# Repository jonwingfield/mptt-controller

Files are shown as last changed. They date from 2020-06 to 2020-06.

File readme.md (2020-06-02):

# MPTT Charge Controller

Reference Design: http://www.ti.com/tool/TIDA-00120

Better Reference Design: http://www.ti.com/lit/ug/tiduej8a/tiduej8a.pdf?&ts=1588978099192

## Resources

- How Buck Converters work (video is super helpful): https://electronicsforu.com/videos-slideshows/diy-buck-converter-tutorial
- DIY MPTT Charge Controller: http://coder-tronics.com/c2000-solar-mppt-tutorial-pt1/. This explains how to build a buck converter that is very efficient (see notes below).
- Fundamentals of MOSFET Driver circuits: http://www.ti.com/lit/ml/slua618/slua618.pdf
- Another DIY. Very mature https://hackaday.io/project/158859-high-efficiency-mppt-solar-charger
- TI Buck Converter Reference: http://www.ti.com/tool/PMP7051C http://www.ti.com/lit/ug/sluu121b/sluu121b.pdf

## Theory of Operation

### Buck Converter

The basics of a buck converter are simple and are well-explained in the above link. Use PWM and a MOSFET to reduce the average voltage. Add an inductor to smooth the current. Add a diode to create a current path when the MOSFET is off. Add a capacitor to smooth the voltage. Finally, some voltage feedback mechanism is necessary to adapt the PWM duty cycle to keep the voltage constant.

#### Component Selection (Inductor and Capacitor)

http://www.onsemi.com/pub/Collateral/AND9135-D.PDF
http://www.ti.com/lit/an/snva038b/snva038b.pdf?ts=1591102835925

#### Efficiency (see resources for overview)

Efficiency Calculation: http://www.ti.com/lit/an/slyt358/slyt358.pdf and https://www.electronicdesign.com/power/fundamentals-buck-converter-efficiency

There a few efficiency problems with the basic buck converter design:

1. The voltage drop of the diode.
2. Output ripple.
3. Switching losses in the MOSFET.

(1) is addressed by replacing the diode with a MOSFET and toggling it opposite the main MOSFET. The main MOSFET is known as the high-side and the other is the low-side. This is called a synchronous buck converter.
(2) is addressed by what's known as an *interleaved* design. This places two circuits in parallel, which supposedly halves the ripple. _TODO: understand why_.
(3) is minimized by a few factors:
1. Low RDS(on) MOSFET.
2. Low Rise/Fall time MOSFET.
3. Selection of switch frequency. A higher frequency will reduce output ripple but increase switching losses, and vise-versa.

Another important consideration is the drive current of the gate driver IC. A higher drive current will switch the MOSFET faster and result in lower switching losses. _TODO: understand why_

Efficiency calculations

### Ringing

http://www.ti.com/lit/an/slpa010/slpa010.pdf

This happens at the gate of the MOSFETs. I don't fully understand why yet, even after reading the above, but it's the reason we need a gate resistor between the driver and the MOSFET.

Also, parasitic inductances and capacitances occur due to the fast switching, so an RC Snubber circuit can be used to mitigate this: http://rohmfs.rohm.com/en/products/databook/applinote/ic/power/switching_regulator/buck_snubber_app-e.pdf

Techniques to reduce ringing: http://www.ti.com/lit/an/slpa010/slpa010.pdf

## Diode Emulation Mode

When the current is low, the inductor current can go negative, resulting in lost efficiency and back current flow into the panel. To prevent this, the sync FET is kept off and uses the body diode to conduct current. This is known as diode emulation mode. 

Important: we also need to use this mode at startup to prevent issues with reverse current flow. See https://en-support.renesas.com/knowledgeBase/4967491. 

See also: http://www.ti.com/lit/ug/tiduan2/tiduan2.pdf?ts=1590949279905

## Appendix A - Notes (because I'm a noob ;)

N-Channel MOSFETs/Transistors are generally used on the ground side of a load. P-Channels on the high side, and are reversed (low = on, high = off).

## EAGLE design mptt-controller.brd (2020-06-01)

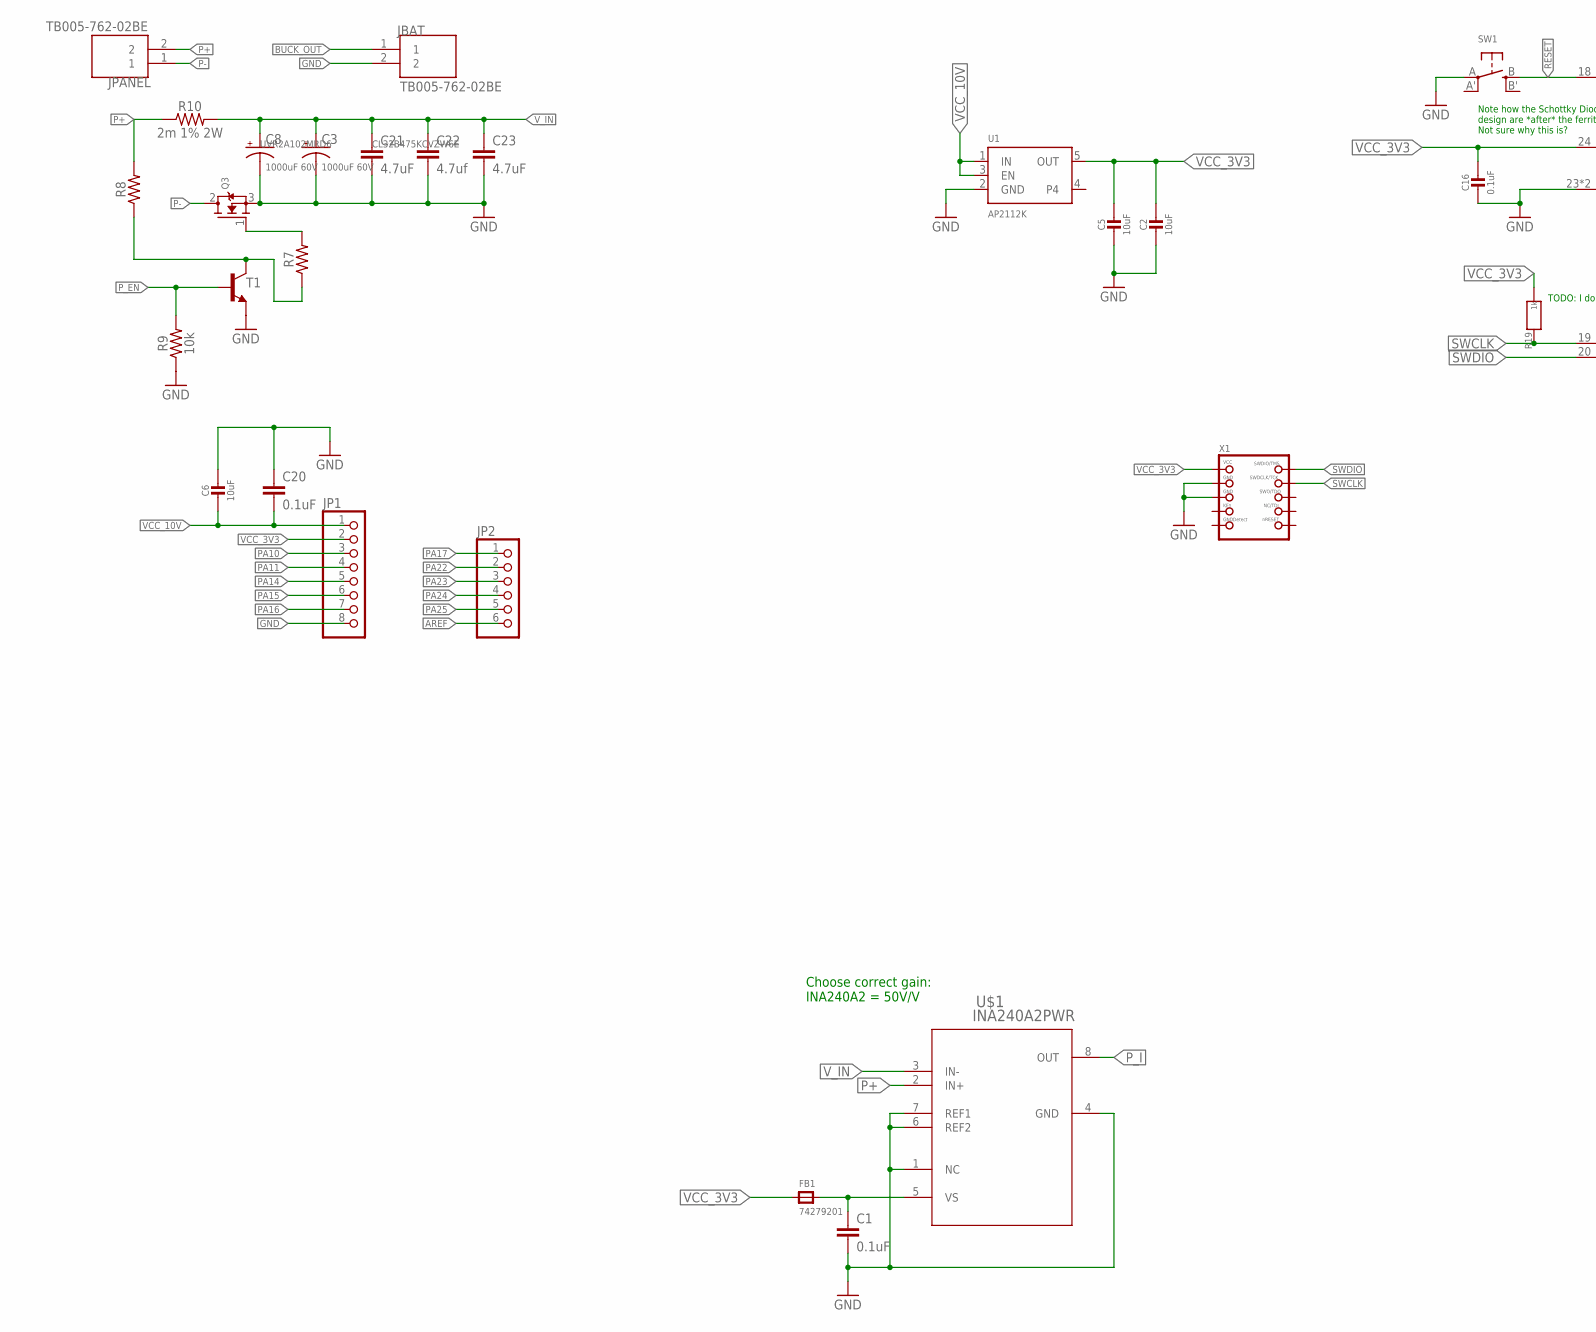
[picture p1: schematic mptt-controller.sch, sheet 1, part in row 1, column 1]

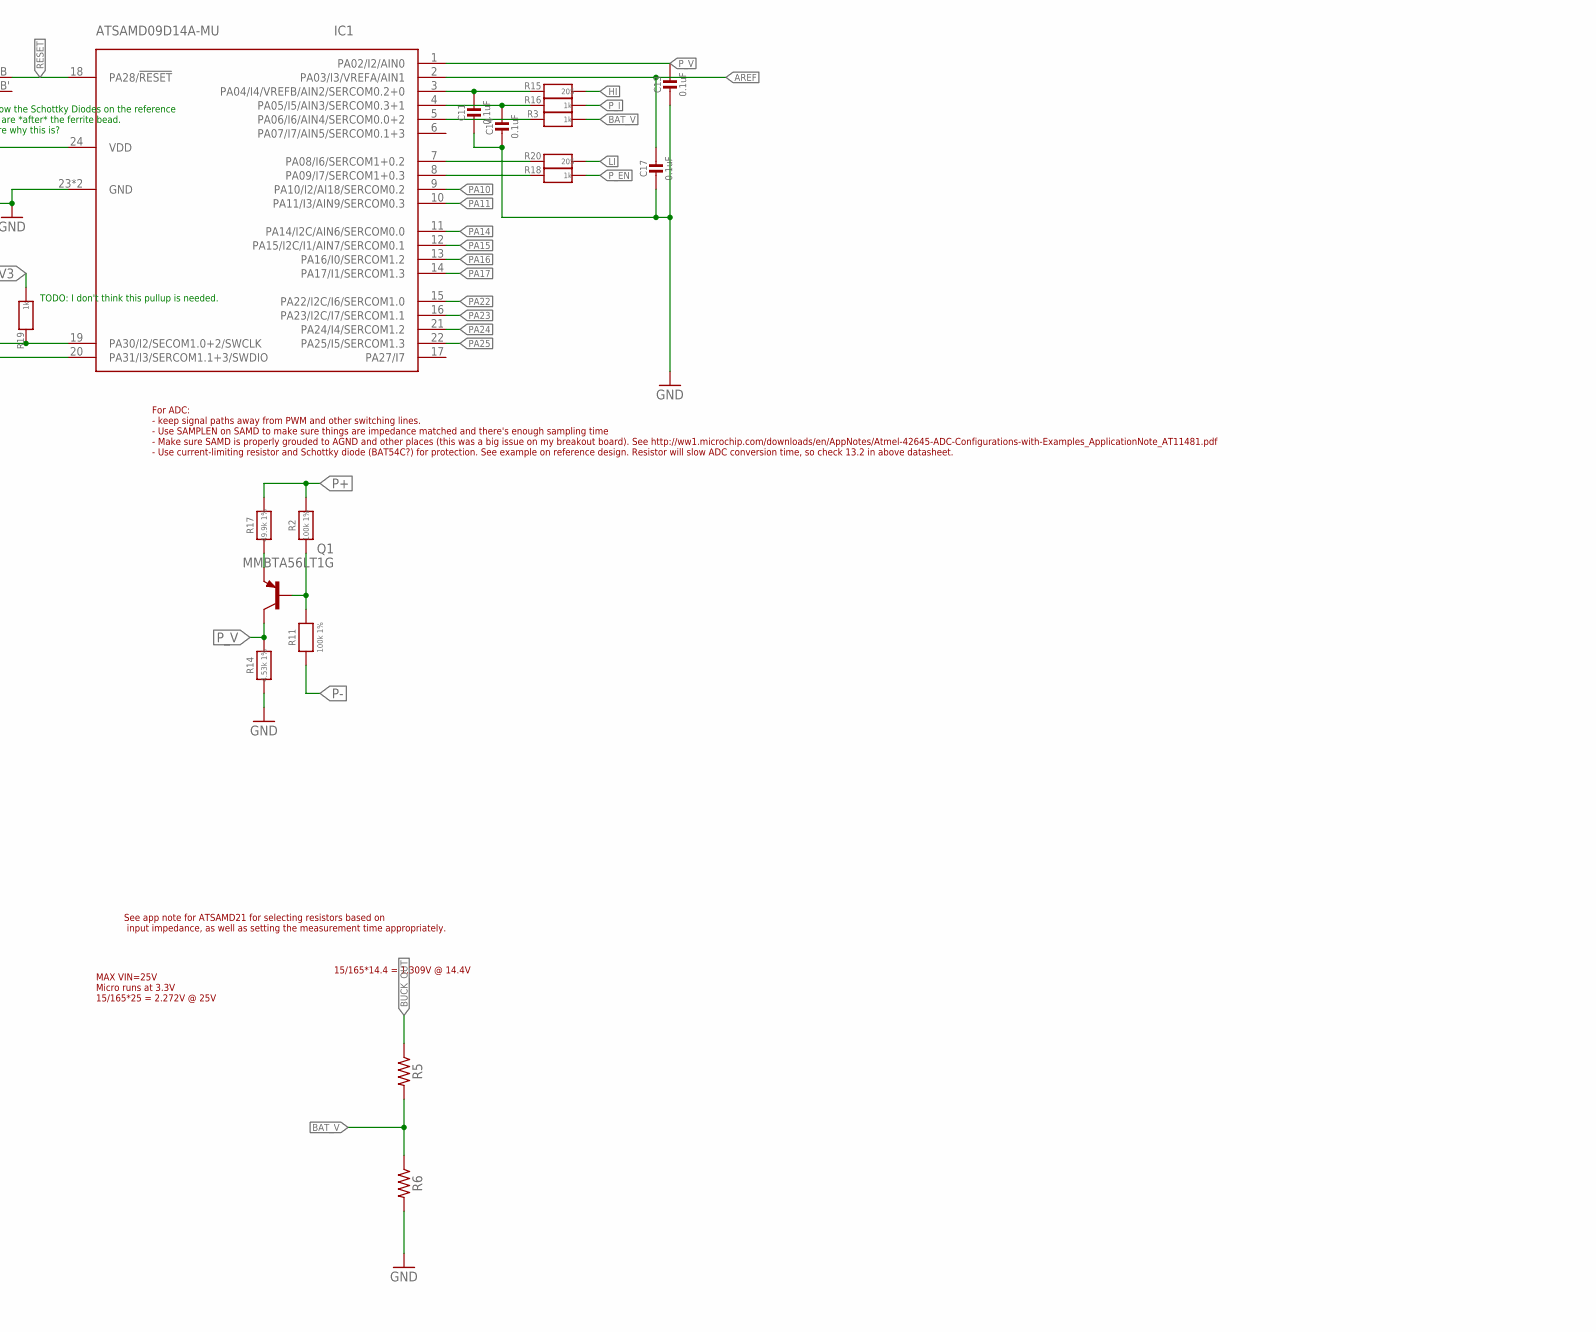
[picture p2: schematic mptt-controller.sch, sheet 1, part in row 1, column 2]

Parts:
C1, C20: 0.1uF; 0603-CAP
C2, C5, C6: 10uF; _0805
C3: 1000uF 60V; CPOL-RADIAL-1000UF-25V
C8: 1000uF 60V; CPOL-RADIAL-1000UF-25V; PARTNUM UVR2A102MRD6
C11, C13, C14, C16, C17: 0.1uF; _0402MP
C21: 4.7uF; C1210; PARTNUM CL32B475KCVZW6E
C22: 4.7uf; C1210
C23: 4.7uF; C1210
FB1: 74279201; _0805
IC1: ATSAMD09D14A-MU; QFN24_4MM
JBAT: TB005-762-02BE; CUI_TB005-762-02BE
JP1: HEADER-1X8ROUND; 1X08_ROUND
JP2: HEADER-1X6ROUND; 1X06_ROUND
JPANEL: TB005-762-02BE; CUI_TB005-762-02BE
Q1: MMBTA56LT1G; SOT23-BEC
Q3: MOSFET-NGDS_TO220V; TO220V
R2, R11: 100k 1%; _0805MP
R3, R16, R18, R19: 1k; _0402MP
R5, R6, R7, R8: 0603
R9: 10k; 0603
R10: 2m 1% 2W; 2512
R14: 4.53k 1%; _0805MP
R15, R20: 205; _0402MP
R17: 49.9k 1%; _0805MP
SW1: SWITCH_TACT_SMT4.6X2.8; BTN_KMR2_4.6X2.8
T1: MMBT3904LT1-NPN-SOT23-BEC; SOT23-BEC
U1: AP2112K; SOT23-5
U$1: INA240A2PWR; PW0008A_N
X1: JTAG-CORTEXBOX; 2X05_1.27MM_BOX_NOPOSTS

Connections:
AREF: C17.1, IC1.2 (PA03/I3/VREFA/AIN1), JP2.6
BAT_V: R3.2, R5.2, R6.1
BUCK_OUT: JBAT.1, R5.1; also elsewhere on the board
GND: C1.2, C2.2, C3.-, C5.2, C6.1, C8.-, C11.2, C13.2, C14.2, C16.2, C17.2, C20.1, C21.2, C22.2, C23.2, IC1.23 (GND), IC1.THERM (GND), JBAT.2, JP1.8, Q3.3 (S), R6.2, R9.1, R14.1, SW1.A, T1.E, U1.2 (GND), U$1.1 (NC), U$1.4 (GND), U$1.6 (REF2), U$1.7 (REF1), X1.3 (GND), X1.5 (GND); also elsewhere on the board
HI: R15.2; also elsewhere on the board
LI: R20.2; also elsewhere on the board
unnamed: IC1.7 (PA08/I6/SERCOM1+0.2), R20.1
unnamed: Q3.1 (G), R7.2
unnamed: IC1.8 (PA09/I7/SERCOM1+0.3), R18.1
unnamed: Q1.B, R2.1, R11.2
unnamed: Q1.E, R17.1
unnamed: C11.1, IC1.3 (PA04/I4/VREFB/AIN2/SERCOM0.2+0), R15.1
unnamed: R7.1, R8.1, T1.C
unnamed: C14.1, IC1.4 (PA05/I5/AIN3/SERCOM0.3+1), R16.1
unnamed: IC1.5 (PA06/I6/AIN4/SERCOM0.0+2), R3.1
P+: JPANEL.2, R2.2, R8.2, R10.P$1 (1), R17.2, U$1.2 (IN+)
P-: JPANEL.1, Q3.2 (D), R11.1
PA10: IC1.9 (PA10/I2/AI18/SERCOM0.2), JP1.3
PA11: IC1.10 (PA11/I3/AIN9/SERCOM0.3), JP1.4
PA14: IC1.11 (PA14/I2C/AIN6/SERCOM0.0), JP1.5
PA15: IC1.12 (PA15/I2C/I1/AIN7/SERCOM0.1), JP1.6
PA16: IC1.13 (PA16/I0/SERCOM1.2), JP1.7
PA17: IC1.14 (PA17/I1/SERCOM1.3), JP2.1
PA22: IC1.15 (PA22/I2C/I6/SERCOM1.0), JP2.2
PA23: IC1.16 (PA23/I2C/I7/SERCOM1.1), JP2.3
PA24: IC1.21 (PA24/I4/SERCOM1.2), JP2.4
PA25: IC1.22 (PA25/I5/SERCOM1.3), JP2.5
P_EN: R9.2, R18.2, T1.B
P_I: R16.2, U$1.8 (OUT)
P_V: C13.1, IC1.1 (PA02/I2/AIN0), Q1.C, R14.2
RESET: IC1.18 (PA28/!RESET), SW1.B (S)
SWCLK: IC1.19 (PA30/I2/SECOM1.0+2/SWCLK), R19.1, X1.4 (SWDCLK)
SWDIO: IC1.20 (PA31/I3/SERCOM1.1+3/SWDIO), X1.2 (SWDIO)
VCC_3V3: C2.1, C5.1, C16.1, FB1.1, IC1.24 (VDD), JP1.2, R19.2, U1.5 (OUT), X1.1 (VCC)
VCC_10V: C6.2, C20.2, JP1.1, U1.1 (IN), U1.3 (EN); also elsewhere on the board
VS: C1.1, FB1.2, U$1.5 (VS)
V_IN: C3.+, C8.+, C21.1, C22.1, C23.1, R10.P$2 (2), U$1.3 (IN-); also elsewhere on the board

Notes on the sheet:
For ADC: - keep signal paths away from PWM and other switching lines. - Use SAMPLEN on SAMD to make sure things are impedance matched and there's enough sampling time - Make sure SAMD is properly grouded to AGND and other places (this was a big issue on my breakout board). See http://ww1.microchip.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
MAX VIN=25V Micro runs at 3.3V 15/165*25 = 2.272V @ 25V
15/165*14.4 = 1.309V @ 14.4V
See app note for ATSAMD21 for selecting resistors based on input impedance, as well as setting the measurement time appropriately.
Choose correct gain: INA240A2 = 50V/V
Note how the Schottky Diodes on the reference design are *after* the ferrite bead. Not sure why this is?
TODO: I don't think this pullup is needed.

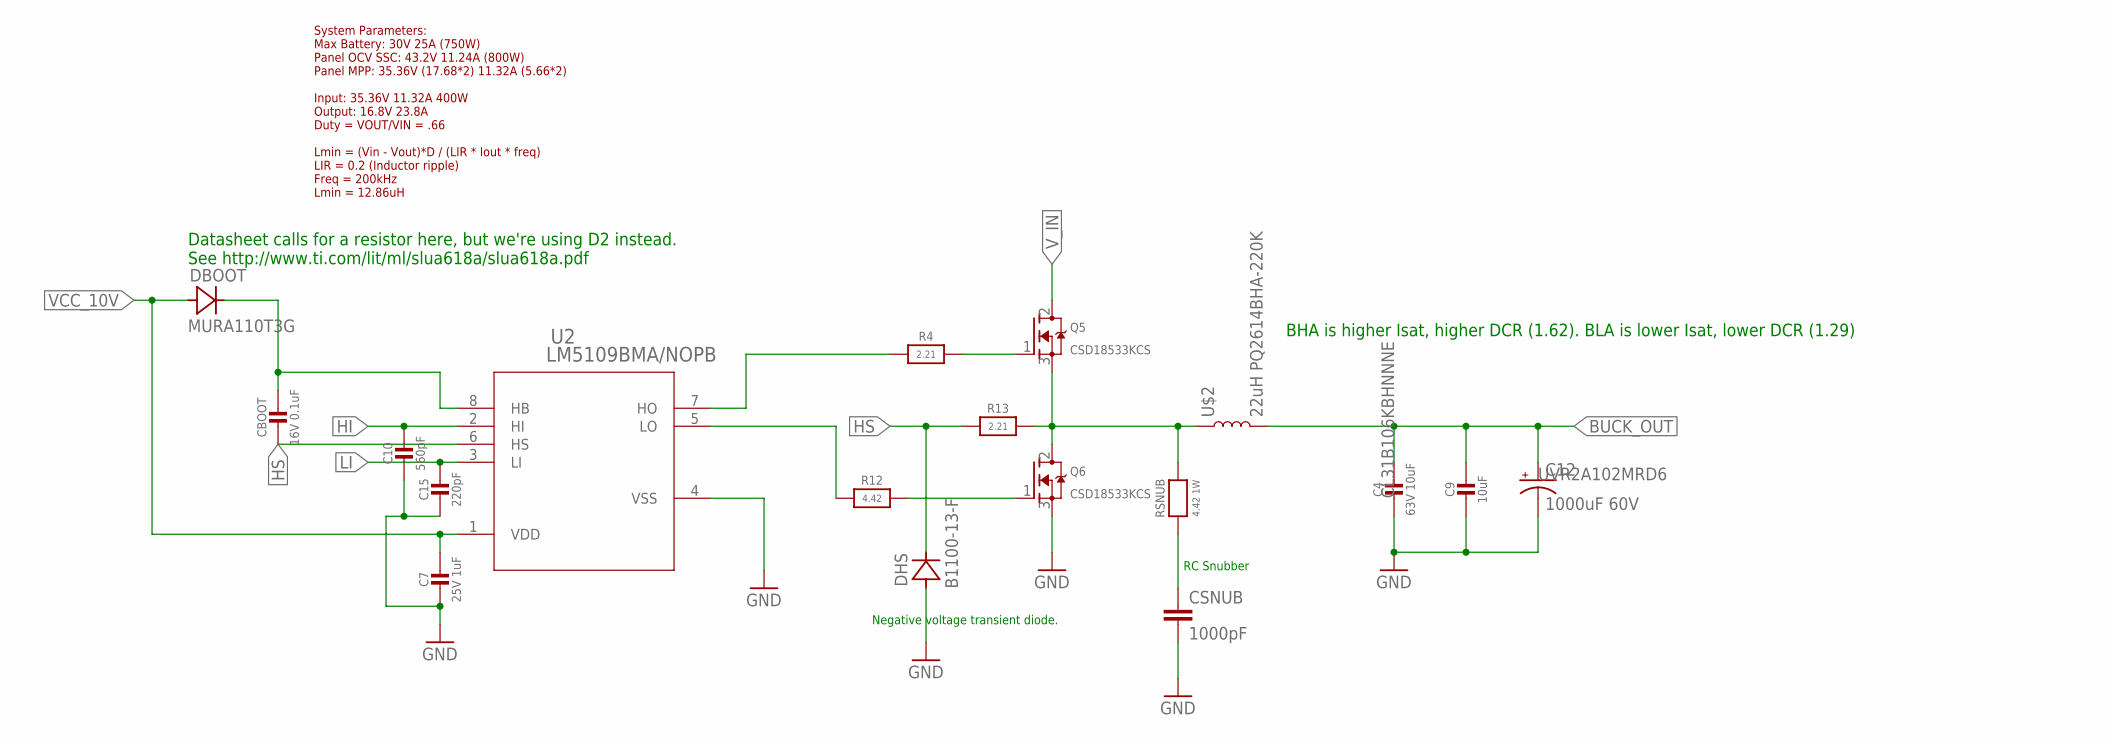
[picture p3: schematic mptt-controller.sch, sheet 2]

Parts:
C4: 63V 10uF; _1206
C7: 25V 1uF; _0805
C9: 10uF; _1206
C10: 560pF; _0603
C12: 1000uF 60V; CPOL-RADIAL-1000UF-25V; PARTNUM UVR2A102MRD6
C15: 220pF; _0603
CBOOT: 16V 0.1uF; _0805
CSNUB: 1000pF; 0603-CAP
DBOOT: MURA110T3G; SMA
DHS: B1100-13-F; SMA
Q5, Q6: CSD18533KCS; TO220V
R4, R13: 2.21; _0805
R12: 4.42; _0805
RSNUB: 4.42 1W; 2512
U2: LM5109BMA/NOPB; M08A_TEX
U$2: 22uH PQ2614BHA-220K; PQ2614

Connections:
BUCK_OUT: C4.1, C9.1, C12.+, U$2.P2 (2); also elsewhere on the board
GND: C4.2, C7.2, C9.2, C10.2, C12.-, C15.2, CSNUB.2, DHS.A, Q6.3 (S), U2.4 (VSS); also elsewhere on the board
HB: CBOOT.1, DBOOT.C, U2.8 (HB)
HI: C10.1, U2.2 (HI); also elsewhere on the board
HO: R4.1, U2.7 (HO)
HS: CBOOT.2, DHS.C, R13.1, U2.6 (HS)
LI: C15.1, U2.3 (LI); also elsewhere on the board
LO: R12.1, U2.5 (LO)
unnamed: Q5.1 (G), R4.2
unnamed: CSNUB.1, RSNUB.1
unnamed: Q6.1 (G), R12.2
SWITCH_NODE: Q5.3 (S), Q6.2 (D), R13.2, RSNUB.2, U$2.P1 (1)
VCC_10V: C7.1, DBOOT.A, U2.1 (VDD); also elsewhere on the board
V_IN: Q5.2 (D); also elsewhere on the board

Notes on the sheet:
RC Snubber
Datasheet calls for a resistor here, but we're using D2 instead. See http://www.ti.com/lit/ml/slua618a/slua618a.pdf
System Parameters: Max Battery: 30V 25A (750W) Panel OCV SSC: 43.2V 11.24A (800W) Panel MPP: 35.36V (17.68*2) 11.32A (5.66*2) Input: 35.36V 11.32A 400W Output: 16.8V 23.8A Duty = VOUT/VIN = .66 Lmin = (Vin - Vout)*D / (LIR * Iout * freq) LIR = 0.2 (Inductor ripple) Freq = 200kHz Lmin = 12.86uH
Negative voltage transient diode.
BHA is higher Isat, higher DCR (1.62). BLA is lower Isat, lower DCR (1.29)

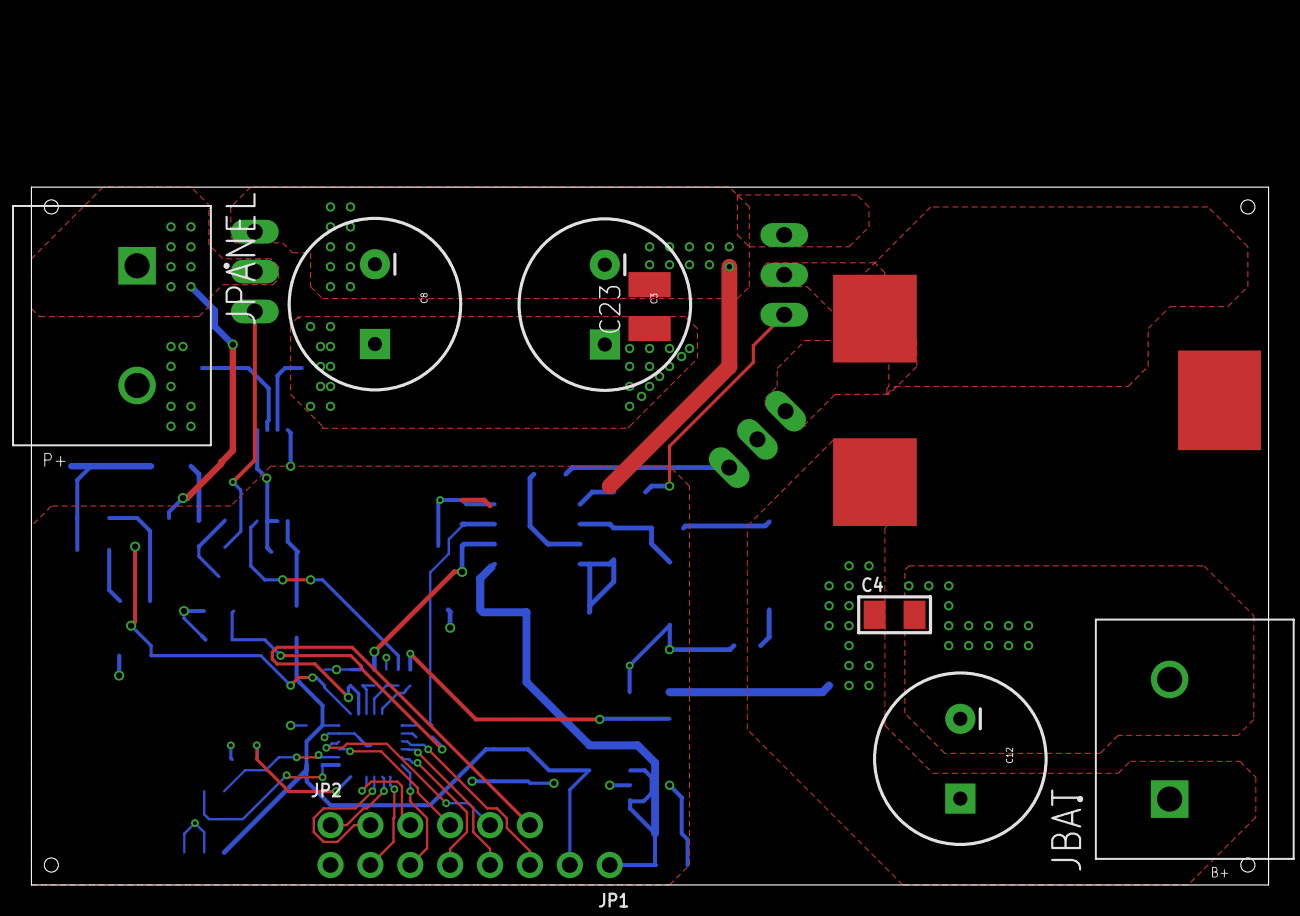
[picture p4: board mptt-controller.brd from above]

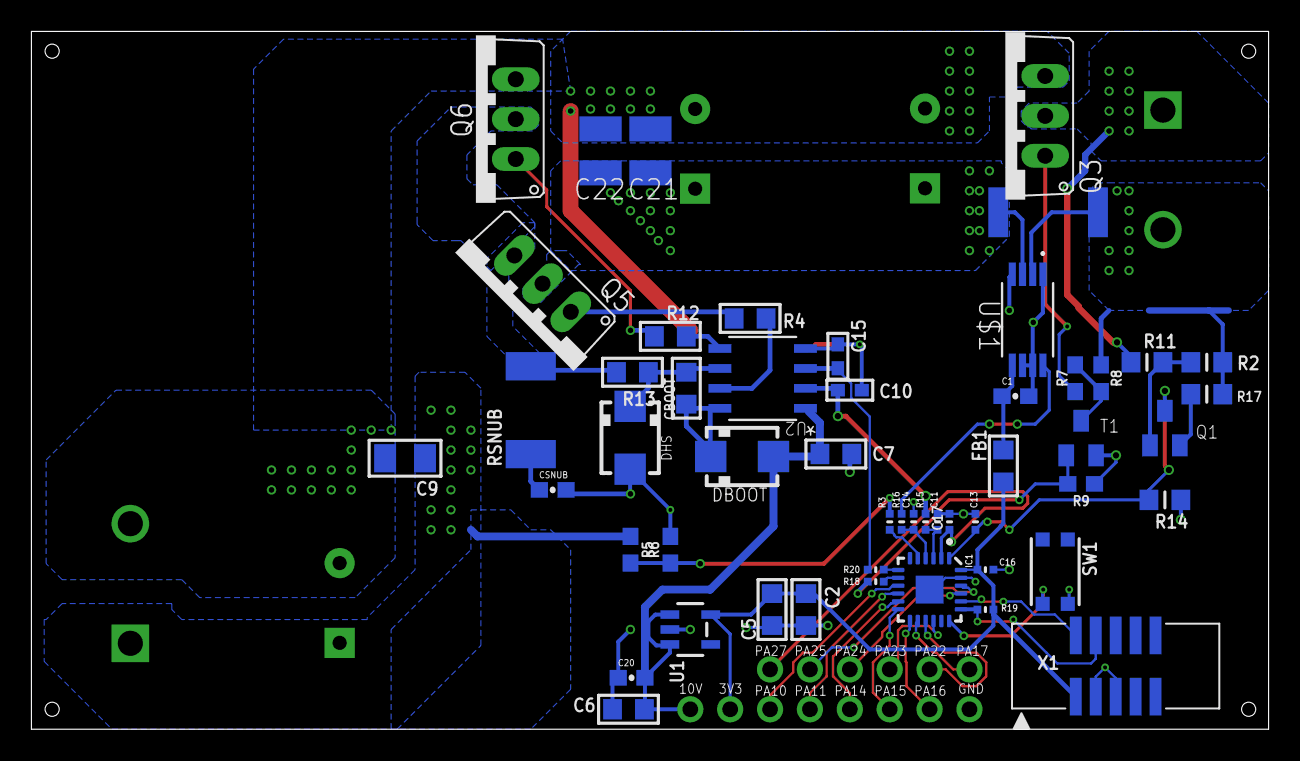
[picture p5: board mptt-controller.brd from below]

Board: 2 copper layers, 78.8 x 44.4 mm, 62 parts (52 on the bottom side), 45 nets.

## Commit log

2018-08-10 Add partially finished schematic.
    [mptt-controller.sch]
2020-05-29 Update for new board. Getting closed to being finished.
    [mptt-controller.brd, mptt-controller.sch]
2020-05-29 Checkpoint - More Vias and polygonal planes.
    [mptt-controller.brd]
2020-05-29 Very close to being finished.
    [mptt-controller.brd, mptt-controller.sch]
2020-05-31 Add information about diode emulation mode.
2020-06-01 Board documentation layer and add a cap for VREFA.
    [mptt-controller.brd, mptt-controller.sch]

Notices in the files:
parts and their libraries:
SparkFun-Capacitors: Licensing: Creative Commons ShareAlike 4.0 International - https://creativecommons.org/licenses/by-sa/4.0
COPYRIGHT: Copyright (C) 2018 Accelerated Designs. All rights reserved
